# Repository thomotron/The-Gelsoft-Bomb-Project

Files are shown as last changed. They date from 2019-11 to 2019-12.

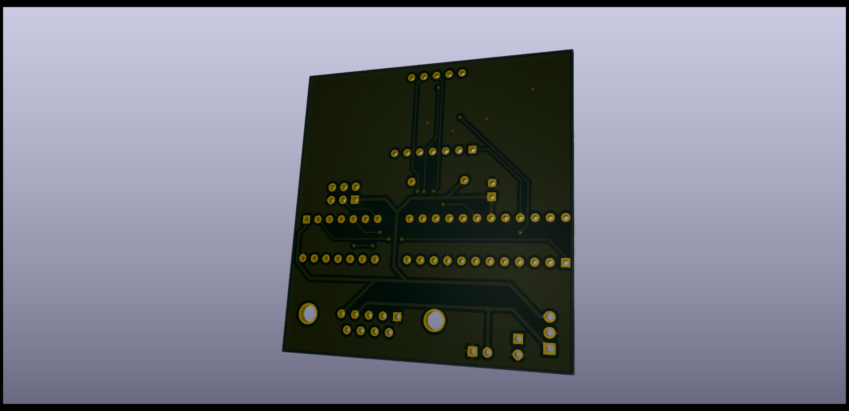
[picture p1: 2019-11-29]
KiCad stuff/The Gelsoft Bomb Project/Case Controller 0.1.0 Back.png

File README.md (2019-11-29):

# The Gelsoft Bomb Project
A [KTANE](https://en.wikipedia.org/wiki/Keep_Talking_and_Nobody_Explodes)-inspired toy bomb for use in [gelsoft](https://en.wikipedia.org/wiki/Gel_ball_shooter) matches.

The core concept is to have a ruggedised case (probably a pistol or camera case like the Pelican Vault V100) that can be opened up to reveal an interactive puzzle and a timer.
If the puzzle is not solved in time, the gelbomb will make a loud beeping noise and stop the timer (sounds lame, but I'm not putting gels in this thing).
This can be incorporated into your own game modes to make things interesting.

The gelbomb It features a highly-modular design, allowing many different puzzle modules to be switched in and out during the course of a day.

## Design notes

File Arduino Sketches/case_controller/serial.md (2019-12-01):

# Core module serial interface
The serial interface with the core module operates on 5v logic using AVR's built-in Universal Serial Interface in three-wire mode (SPI-compatible).
The core module acts as the master serial device, so it provides its own clock source.

Communication is started by first sending a single-byte command from the command table below:

| 7 (MSB) | 6 | 5 | 4 | 3 | 2 | 1 | 0 (LSB) | Command |
| --- | - | - | - | - | - | - | --- | --- |
| 0 | 0 | 0 | 0 | 0 | 0 | 0 | 0 | Do nothing |
| 0 | 0 | 0 | 0 | 0 | 0 | 0 | 1 | Defuse |
| 0 | 0 | 0 | 0 | 0 | 0 | 1 | 0 | Detonate |
| 0 | 0 | 0 | 0 | 0 | 0 | 1 | 1 | Add strike |
| 0 | 0 | 0 | 0 | 0 | 1 | 0 | 0 | Add time |
| 0 | 0 | 0 | 0 | 0 | 1 | 0 | 1 | Remove time |
| 1 | 0 | 0 | 0 | 0 | 1 | 1 | 0 | Get strikes |
| 1 | 0 | 0 | 0 | 0 | 1 | 1 | 1 | Get time remaining  |
| 1 | 0 | 0 | 0 | 1 | 0 | 0 | 0 | Get low power state |

Data is sent as another byte following the command which may be either to or from the core module.
The most-significant bit denotes whether the data will be sent by the core module (Bit 7 = 1) or the puzzle module (Bit 7 = 0).

# Commands
## Defuse
**Command:** `0b00000001`  
**Payload:** No  
Defuses the device, stopping the timer. The device will not accept commands that modify its state while defused.

## Detonate
**Command:** `0b00000010`  
**Payload:** No  
Detonates the device, adding the maximum number of strikes and stopping the timer. The device will not accept commands that modify its state while detonated.

## Add strike
**Command:** `0b00000011`  
**Payload:** No  
Adds one strike. If the number of strikes exceeds the maximum, the device will detonate.

## Add time
**Command:** `0b00000100`  
**Payload:** Yes  
**Direction:** Puzzle-to-core  
Adds up to 5999 seconds to the timer. The timer will not exceed 5999 seconds.
Because this is larger than an 8-bit unsigned integer, the value may be split over two bytes with 7 bits of data each.
The most-significant bit of each byte is used as a flag to expect a following byte with additional data.
If the first byte given has the most-significant bit set to 1, the given bits are shifted left 7 places and another byte will be expected with the remaining 7 bits of data.
These bits are shifted MSB-first into a 16-bit unsigned integer.

**Payload format table:**

| 7 (MSB) | 6 | 5 | 4 | 3 | 2 | 1 | 0 (LSB) | Command |
| --- | - | - | - | - | - | - | --- | --- |
| 0 | a | b | c | d | e | f | g | Add the given bits to the timer |
| 1 | a | b | c | d | e | f | g | Shift bits 0-6 and await 7 more |

## Remove time
**Command:** `0b00000101`  
**Payload:** Yes  
**Direction:** Puzzle-to-core  
Removes up to 5999 seconds from the timer. The timer will not drop below 0 seconds.
Because this is larger than an 8-bit unsigned integer, the value may be split over two bytes with 7 bits of data each.
The most-significant bit of each byte is used as a flag to expect a following byte with additional data.
If the first byte given has the most-significant bit set to 1, the given bits are shifted left 7 places and another byte will be expected with the remaining 7 bits of data.
These bits are shifted MSB-first into a 16-bit unsigned integer.

**Payload format table:**

| 7 (MSB) | 6 | 5 | 4 | 3 | 2 | 1 | 0 (LSB) | Command |
| --- | - | - | - | - | - | - | --- | --- |
| 0 | a | b | c | d | e | f | g | Remove the given bits from the timer |
| 1 | a | b | c | d | e | f | g | Shift bits a-g and await 7 more |

## Get strikes
**Command:** `0b10000110`  
**Payload:** Yes  
**Direction:** Core-to-puzzle  
Gets the current number of strikes as an 8-bit unsigned integer.

**Payload format table:**

| 7 (MSB) | 6 | 5 | 4 | 3 | 2 | 1 | 0 (LSB) | Command |
| --- | - | - | - | - | - | - | --- | --- |
| a | b | c | d | e | f | g | h | Number of strikes |

## Get time remaining
**Command:** `0b10000111`  
**Payload:** Yes  
**Direction:** Core-to-puzzle  
Gets the current amount of time remaining.
Because this is larger than an 8-bit unsigned integer, the value may be split over two bytes with 7 bits of data each.
The most-significant bit of each byte is used as a flag to expect a following byte with additional data.
If the first byte received has the most-significant bit set to 1, the remaining bits are shifted left 7 places and another byte should be expected with the remaining 7 bits of data.
These bits should be shifted MSB-first into a 16-bit unsigned integer.

**Payload format table:**

| 7 (MSB) | 6 | 5 | 4 | 3 | 2 | 1 | 0 (LSB) | Command |
| --- | - | - | - | - | - | - | --- | --- |
| 0 | a | b | c | d | e | f | g | Remaining time |
| 1 | a | b | c | d | e | f | g | Shift bits a-g and await 7 more |

## Get low power state
**Command:** `0b10001000`  
**Payload:** Yes  
**Direction:** Core-to-puzzle  
Gets whether the device is in low-power mode. When the device is in low-power mode, all high-current

**Payload format table:**

| 7 (MSB) | 6 | 5 | 4 | 3 | 2 | 1 | 0 (LSB) | Command |
| --- | - | - | - | - | - | - | --- | --- |
| X | X | X | X | X | X | X | 1 | Low power is enabled  |
| X | X | X | X | X | X | X | 0 | Low power is disabled |

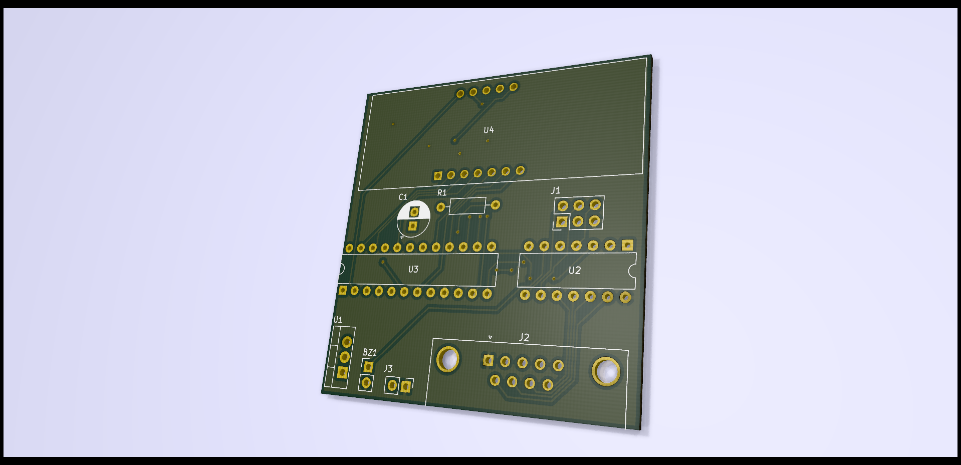
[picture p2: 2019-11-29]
KiCad stuff/The Gelsoft Bomb Project/Case Controller 0.1.0 Front.png

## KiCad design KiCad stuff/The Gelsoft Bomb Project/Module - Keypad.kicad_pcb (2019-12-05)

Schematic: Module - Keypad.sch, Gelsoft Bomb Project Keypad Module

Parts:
J1: ISP; PinHeader_2x03_P2.54mm_Vertical
J2: Module Connector; PinHeader_1x09_P1.27mm_Vertical
R1: 10k; R_Axial_DIN0614_L14.3mm_D5.7mm_P20.32mm_Horizontal
U1: ATmega8-16PU; DIP-28_W7.62mm
U2: 74HC595; DIP-16_W7.62mm
U3: 3x4_Keypad; PinHeader_1x07_P2.54mm_Vertical
U4: MC11605A6W7-BNMLW; PinHeader_1x16_P2.54mm_Vertical

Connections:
5v: J1.1, J2.9, U1.7 (VCC), U2.16 (VCC), U4.2, U4.15
Earth: J1.5, J2.1, J2.2, J2.6, J2.7, R1.2, U1.8 (GND), U2.8 (GND), U4.1
MISO: J1.2, J2.4, U1.18 (PB4)
MOSI: J1.3, J2.3, U1.17 (PB3)
unnamed: R1.1, U4.3
unnamed: U1.2 (PD0), U4.6
unnamed: U1.3 (PD1), U3.3
unnamed: U1.4 (PD2), U3.1
unnamed: U1.5 (PD3), U3.5
unnamed: U1.6 (PD4), U3.2
unnamed: U1.10 (PB7/XTAL2), U2.10 (~SRCLR)
unnamed: U1.11 (PD5), U3.7
unnamed: U1.12 (PD6), U3.6
unnamed: U1.13 (PD7), U3.4
unnamed: U1.23 (PC0), U2.14 (SER)
unnamed: U1.24 (PC1), U2.11 (SRCLK)
unnamed: U1.25 (PC2), U2.12 (RCLK)
unnamed: U1.26 (PC3), U4.16
unnamed: U1.27 (PC4), U4.4
unnamed: U1.28 (PC5), U4.5
unnamed: U2.1 (QB), U4.8
unnamed: U2.2 (QC), U4.9
unnamed: U2.3 (QD), U4.10
unnamed: U2.4 (QE), U4.11
unnamed: U2.5 (QF), U4.12
unnamed: U2.6 (QG), U4.13
unnamed: U2.7 (QH), U4.14
unnamed: U2.15 (QA), U4.7
RESET: J1.6, U1.1 (PC6/~RESET)
SCK: J1.4, J2.5, U1.19 (PB5)
VIN: J2.8

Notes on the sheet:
Keypad
LCD Enable
Shift Reg.
LCD Mode/LED

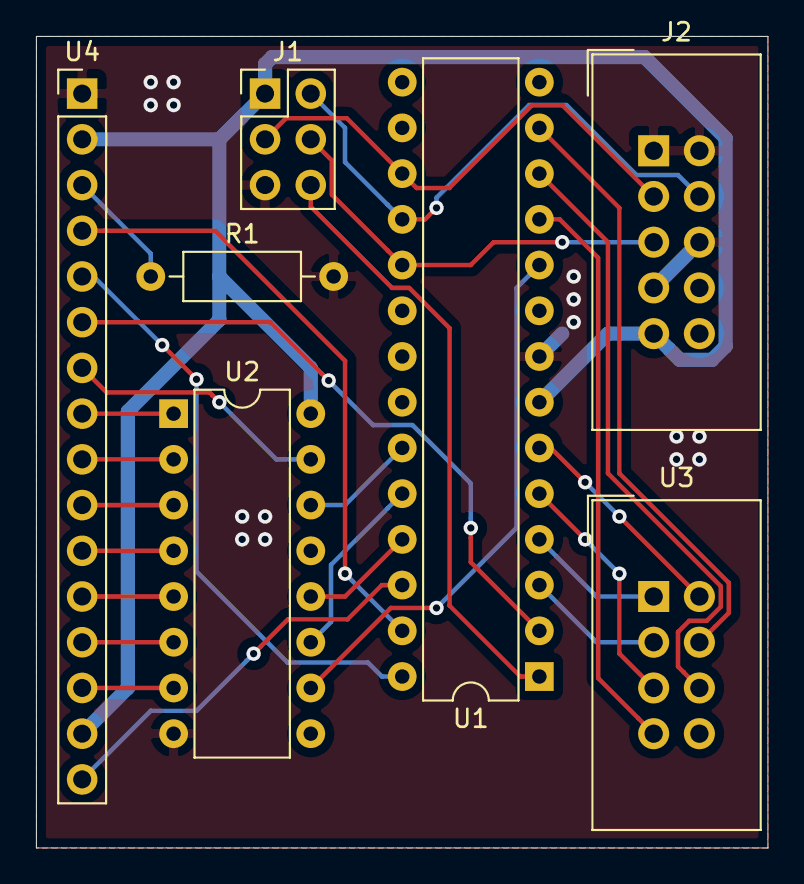
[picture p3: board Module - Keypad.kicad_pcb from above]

Board: 2 copper layers, 40.6 x 45.1 mm, 7 parts (0 on the bottom side), 30 nets.

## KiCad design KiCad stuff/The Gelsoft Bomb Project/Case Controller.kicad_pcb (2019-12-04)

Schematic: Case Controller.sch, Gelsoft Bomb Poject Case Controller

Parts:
BZ1: Buzzer; PinHeader_1x02_P2.54mm_Vertical
C1: 470uF; CP_Radial_D10.0mm_P5.00mm
D1: 1N5400; D_DO-201AD_P15.24mm_Horizontal
D2: STRIKE 1; LED_Square_15x15mm
D3: STRIKE 2; LED_Square_15x15mm
J1: ISP; PinHeader_2x03_P2.54mm_Vertical
J2: Module Connector; DSUB-9_Male_Horizontal_P2.77x2.84mm_EdgePinOffset4.94mm_Hou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
J3: Battery Header; PinHeader_1x02_P2.54mm_Vertical
J4: Low-Power Switch; PinHeader_1x02_P2.54mm_Vertical
R1: 20k; R_Axial_DIN0207_L6.3mm_D2.5mm_P10.16mm_Horizontal
R5, R6, R7, R8: 100k; R_Axial_DIN0207_L6.3mm_D2.5mm_P10.16mm_Horizontal
SW1: Power Switch; SK12D07VG3
SW2: PLUS; SW_PUSH_6mm
SW3: MINUS; SW_PUSH_6mm
SW4: OK; SW_PUSH_6mm
U1: Buck_Converter_Module_7-26v; Buck_Converter_Module_7-24v
U2: ATtiny24A-PU; DIP-14_W7.62mm
U3: MAX7219; DIP-24_W7.62mm
U4: HDSP-B09G; HDSP-B08G

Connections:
5v: C1.1, J1.1, J2.9, R1.2, R5.2, SW2.1, SW3.1, SW4.1, U1.3, U2.1, U3.19
BUZZER: BZ1.1, U2.6
Earth: BZ1.2, C1.2, J1.5, J2.1, J2.2, J2.6, J2.7, J3.1, U1.2, U1.4, U2.14, U3.4, U3.9
LOWPOWER: J4.1, U2.13
MINUS: R7.1, U2.11
MISO: J1.2, J2.4, U2.8
MOSI: J1.3, J2.3, U2.7
unnamed: D1.2, SW1.1
unnamed: D2.1, U3.2, U4.12
unnamed: D2.2, D3.2, U3.22, U4.3
unnamed: D3.1, U3.7, U4.6
unnamed: J3.2, SW1.2
unnamed: J4.2, R5.1
unnamed: R1.1, U3.18
unnamed: R6.2, SW2.2
unnamed: R7.2, SW3.2
unnamed: R8.2, SW4.2
unnamed: U2.2, U3.1
unnamed: U2.3, U3.13
unnamed: U2.5, U3.12
unnamed: U3.6, U4.8
unnamed: U3.11, U4.9
unnamed: U3.14, U4.11
unnamed: U3.15, U4.10
unnamed: U3.16, U4.7
unnamed: U3.17, U4.5
unnamed: U3.20, U4.4
unnamed: U3.21, U4.1
unnamed: U3.23, U4.2
OK: R8.1, U2.10
PLUS: R6.1, U2.12
RESET: J1.6, U2.4
SCK: J1.4, J2.5, U2.9
VIN: D1.1, J2.8, U1.1

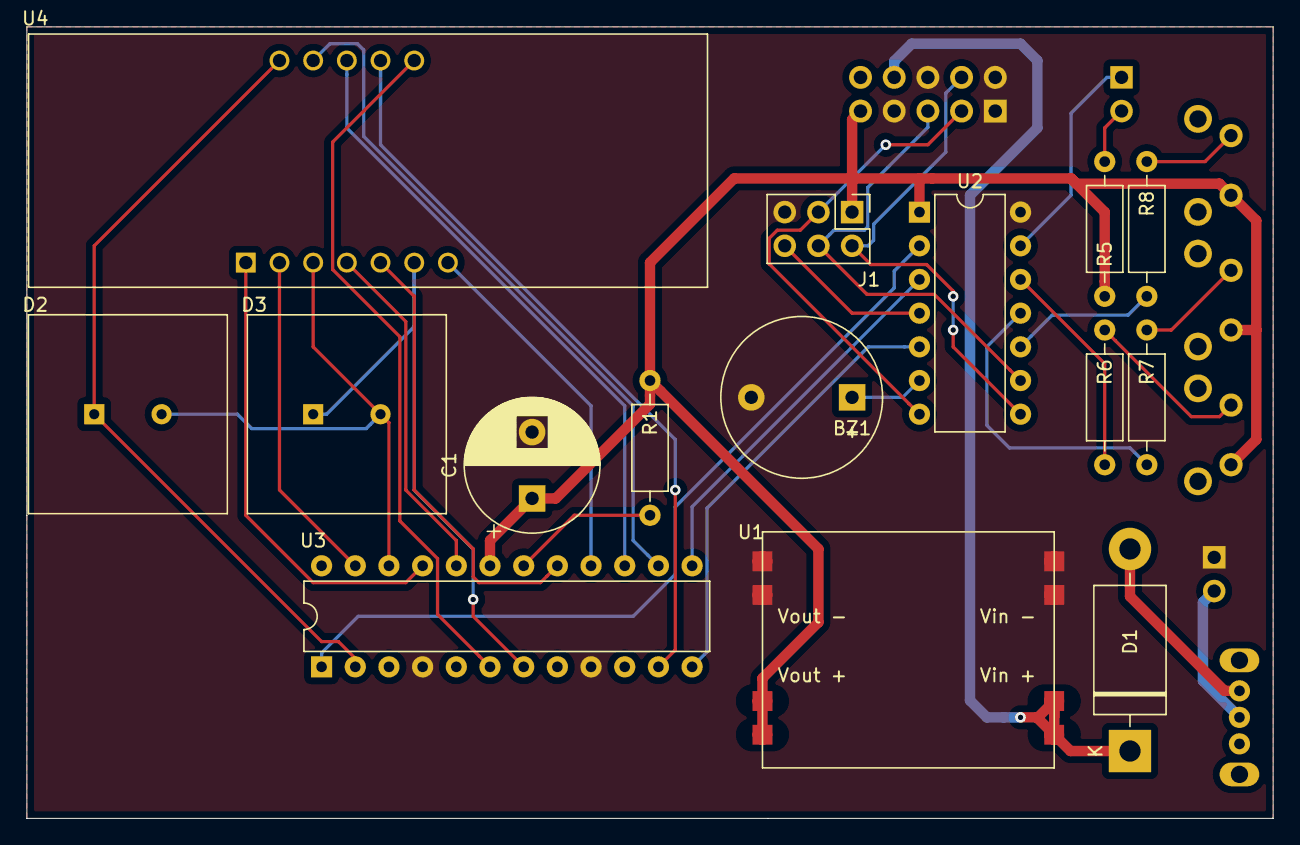
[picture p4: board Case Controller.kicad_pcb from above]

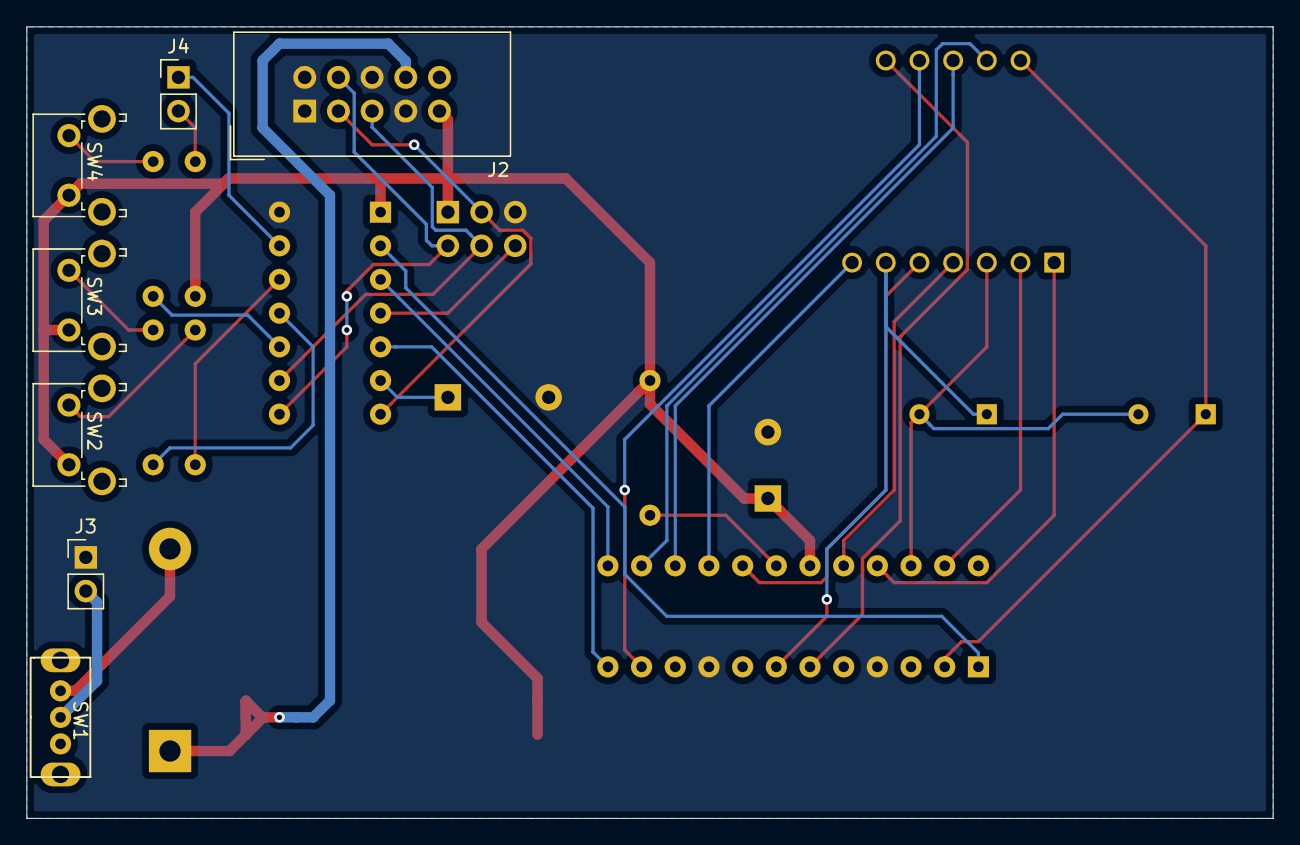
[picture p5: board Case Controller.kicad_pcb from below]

Board: 2 copper layers, 94.0 x 59.7 mm, 22 parts (7 on the bottom side), 34 nets.

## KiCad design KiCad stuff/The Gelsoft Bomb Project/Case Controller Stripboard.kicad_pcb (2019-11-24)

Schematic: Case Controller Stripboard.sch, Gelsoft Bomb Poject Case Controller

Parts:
BZ1: Buzzer; PinHeader_1x02_P2.54mm_Vertical
C1: 100uF; CP_Radial_D6.3mm_P2.50mm
J1: ISP; PinHeader_2x03_P2.54mm_Vertical
J2: Module Connector; DSUB-9_Male_Horizontal_P2.77x2.84mm_EdgePinOffset4.94mm_Hou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
J3: Battery Header; PinHeader_1x02_P2.54mm_Vertical
J4, J5: Conn_01x07; PinSocket_1x07_P2.54mm_Vertical
R1: 20k; R_Axial_DIN0207_L6.3mm_D2.5mm_P10.16mm_Horizontal
U1: L7805; TO-220-4_Vertical
U2: ATtiny24A-PU; DIP-14_W7.62mm
U3: MAX7219; DIP-24_W7.62mm
U4: HDSP-B09G; HDSP-B08G

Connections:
5v: C1.1, J1.1, J2.5, J4.1, R1.2, U1.3, U2.1, U3.19
BUZZER: BZ1.1, J4.6, U2.6
CORRECT: J2.6, J5.6, U2.13
DISARM: J2.8, J5.4, U2.11
GND: BZ1.2, C1.2, J2.1, J3.1, J5.7, U1.2, U2.14, U3.4, U3.9
LOWPOWER: J2.9, J5.3, U2.10
MISO: J5.1, U2.8
MOSI: J4.7, U2.7
unnamed: R1.1, U3.18
unnamed: U3.2, U4.12
unnamed: U3.6, U4.8
unnamed: U3.7, U4.6
unnamed: U3.11, U4.9
unnamed: U3.14, U4.11
unnamed: U3.15, U4.10
unnamed: U3.16, U4.7
unnamed: U3.17, U4.5
unnamed: U3.20, U4.4
unnamed: U3.21, U4.1
unnamed: U3.22, U4.3
unnamed: U3.23, U4.2
Pin2: J4.2, U2.2, U3.1
Pin3: J4.3, U2.3, U3.13
Pin5: J4.5, U2.5, U3.12
RESET: J4.4, U2.4
SCK: J5.2, U2.9
STRIKE: J2.7, J5.5, U2.12
VIN: J2.4, J3.2, U1.1

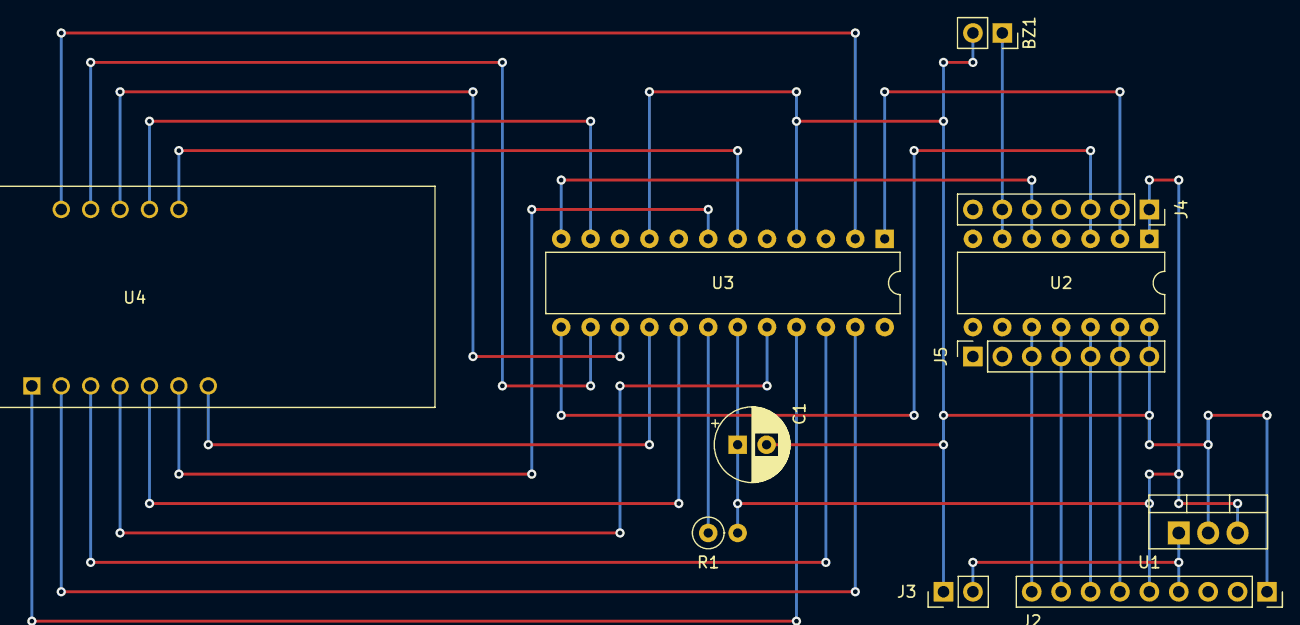
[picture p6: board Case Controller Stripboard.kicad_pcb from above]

Board: 2 copper layers, 11 parts (0 on the bottom side), 28 nets.

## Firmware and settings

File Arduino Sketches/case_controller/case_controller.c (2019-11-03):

// This file is written to correspond with the
// following pinout:
//
//                    ATTiny24A
//                   .----v----.
//              Vcc -| 1    14 |- GND
// B0   MAX7219 DIN -| 2    13 |- CORRECT IN    A0
// B1   MAX7219 CLK -| 3    12 |- STRIKE IN     A1
// B3     ISP RESET -| 4    11 |- DISARM OUT    A2
// B2  MAX7219 LOAD -| 5    10 |- LOWPOWER OUT  A3
// A7        BUZZER -| 6     9 |- ISP SCK       A4
// A6      ISP MOSI -| 7     8 |- ISP MISO      A5
//                   *---------*

#include <avr/io.h>
#include <avr/interrupt.h>
#include <util/delay.h>
#include <stdbool.h>
#include "max7219.c"

// Define some macros for the DIN, CLK, and LOAD connections to the MAX2719
#define DIN_PORT PORTB
#define DIN_PIN  0
#define CLK_PORT PORTB
#define CLK_PIN  1
#define LOAD_PORT PORTB
#define LOAD_PIN 2

// Define some macros for the interrupt pins
#define CORRECT_PORT PORTA
#define CORRECT_PIN  0
#define STRIKE_PORT PORTA
#define STRIKE_PIN  1

// Define some macros for other pins
#define BUZZER_PORT PORTA
#define BUZZER_PIN 7

// Function prototypes
void init();
void onCorrect();
void onStrike();
void enableInterrupts();
void disableInterrupts();
void enableInterrupt(int interrupt);
void disableInterrupt(int interrupt);
void writeBit(bool bit);
void writeByteMSB(unsigned char byte);
void displayTimeRemaining();
void updateDisplay();
void beep(int duration);

// State variables
bool running = true;
volatile bool solved = false;
volatile int strikes = 0;
const int maxStrikes = 3;
int timeRemaining = 300; // 5-minute countdown
bool displayBlinking = false;
bool displayBlankedLast = false;

// Interrupt states
bool correctPinLast;
bool strikePinLast;

// Define interrupt handler
ISR(PCINT0_vect)
{
    // Get current interrupt pin states
    bool correctPin = (CORRECT_PORT >> CORRECT_PIN) & 1;
    bool strikePin = (STRIKE_PORT >> STRIKE_PIN) & 1;

    // Compare and run handlers
    if (correctPinLast != correctPin) onCorrect();
    if (strikePinLast != strikePin) onStrike();

    // Shift states to history for the next run
    correctPinLast = correctPin;
    strikePinLast = strikePin;
}

void init()
{
    // Set port I/O directions
    DDRA |= 0b11000000;
    DDRB |= 0b00000000;

    // Set up interrupt registers and enable PCINT0 and PCINT1
    enableInterrupts();
    enableInterrupt(0);
    enableInterrupt(1);

    // Initialise the LED display
    MAX7219_Init();

    // Test the display for one second
    MAX7219_DisplayTestStart();
    _delay_ms(1000);
    MAX7219_DisplayTestStop();
    MAX7219_Clear();
}

int main() {
    // Initialise everything
    init();

    // Enter the Main Run Loop (MRL) -- Advanced military tech right here
    while (running)
    {
        int delay_ms = 1000;

        // Decrement time remaining by 1 second
        timeRemaining--;

        // Update the display based on our current state
        updateDisplay();

        // Check if we should detonate
        if (timeRemaining < 0 || strikes == maxStrikes)
        {
            // Disable interrupts and clear running flag
            disableInterrupt(0);
            disableInterrupt(1);
            running = false;

            // TODO: Detonate more spectacularly
            // For now, we'll just make a nice long beep
            beep(3000);

            // Reached an end condition, break out
            break;
        }
        // Check if we've been solved
        else if (solved)
        {
            // Disable interrupts and clear running flag
            disableInterrupt(0);
            disableInterrupt(1);
            running = false;

            // Reached an end condition, break out
            break;
        }

        // Beep the buzzer if running
        if (timeRemaining >= 0) {
            beep(50);
            delay_ms -= 50;
        }

        // Wait until we have no delay left
        while (delay_ms-- > 0) _delay_ms(1);
    }

    // Loop forever until we're reset
    while (true) continue;
}

void updateDisplay()
{
    // Blinking logic
    // Check if this is the blanking part of the blink cycle if we are blinking
    if (displayBlinking && !displayBlankedLast)
    {
        // Blank the display and set the blanked flag
        MAX7219_Clear();
        displayBlankedLast = true;

        // Stop here
        return;
    }
    else
    {
        // Reset the blanked flag
        displayBlankedLast = false;
    }

    // Actually update the display with content
    // Check which message we should display
    if (strikes == maxStrikes || timeRemaining < 0) // Are we dead?
    {
        // Write 'DEAD'
        MAX7219_DisplayChar(1, 'D', false);
        MAX7219_DisplayChar(2, 'E', false);
        MAX7219_DisplayChar(3, 'A', false);
        MAX7219_DisplayChar(4, 'D', false);
    }
    else
    {
        // Write remaining time
        displayTimeRemaining();
    }
}

void displayTimeRemaining()
{
    // Check if we have passed the point of no return
    if (timeRemaining < 0)
    {
        // 'Line-out' the display since we can't do negative numbers
        for (int i = 1; i <= 4; i++)
        {
            MAX7219_DisplayChar(i, '-', false);
        }
    }
    else
    {
        // Split the remaining time down into digits and display them
        int minutes = timeRemaining / 60;
        int seconds = timeRemaining - (minutes * 60);
        MAX7219_DisplayChar(1, (char) ((int)(minutes / 10) + 48), false); // Values are offset by 48 for ASCII
        MAX7219_DisplayChar(2, (char) ((int)(minutes % 10) + 48), true); // DP enabled to show a ':'
        MAX7219_DisplayChar(3, (char) ((int)(seconds / 10) + 48), true); // between digits 2 and 3
        MAX7219_DisplayChar(4, (char) ((int)(seconds % 10) + 48), false);
    }
}

void onCorrect()
{
    solved = true;
}

void onStrike()
{
    strikes = ++strikes > maxStrikes ? maxStrikes : strikes; // Cap strikes at maxStrikes
}

void enableInterrupts()
{
    // Enable global interrupts by setting SREG[7] to 1
    SREG |= (1 << 7);

    // Enable interrupt group PCINT[0-7] by setting GIMSK[4] to 1
    GIMSK |= (1 << 4);
}

void disableInterrupts()
{
    // Disable global interrupts by setting SREG[7] to 0
    SREG &= ~(1 << 7);

    // Disable interrupt group PCINT[0-7] by setting GIMSK[4] to 0
    GIMSK &= ~(1 << 4);
}

// Enables an interrupt pin in the PCINT[0-7] group
void enableInterrupt(int interrupt)
{
    // Enable interrupt pin by setting PCMSK0[interrupt] to 1
    PCMSK0 |= (1 << interrupt);
}

// Disables an interrupt pin in the PCINT[0-7] group
void disableInterrupt(int interrupt)
{
    // Disable interrupt pin by setting PCMSK0[interrupt] to 0
    PCMSK0 &= ~(1 << interrupt);
}

// Writes a single bit to the given port on the given pin
//   bit: Bit to write
void writeBit(bool bit)
{
    // Set or clear the pin, depending on the bit
    if (bit) DIN_PORT |= bit << DIN_PIN;
    else DIN_PORT &= ~(bit << DIN_PIN);

    // Pulse the clock
    CLK_PORT |= 1 << CLK_PIN;
    CLK_PORT &= ~(1 << CLK_PIN);
}

// Writes a single byte to the given port on the given pin (MSB-first)
//   byte: Byte to write
void writeByteMSB(unsigned char byte)
{
    // Iterate from MSB to LSB
    for (int i = 7; i >= 0; i--)
    {
        // Mask the relevant bit and write it
        writeBit(byte & (1 << i));
    }
}

// Beeps for the given number of milliseconds
void beep(int duration)
{
    // Write the pin high
    BUZZER_PORT |= 1 << BUZZER_PIN;

    // Hacky workaround for runtime-variable delay
    while (duration-- > 0) _delay_ms(1);

    // Write the pin low
    BUZZER_PORT &= ~(1 << BUZZER_PIN);
}

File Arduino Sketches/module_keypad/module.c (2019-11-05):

// This file is written to correspond with the
// following pinout:
//
//                     ATMega8
//                   .----v----.
// C6         RESET -| 1    28 |- LCD R/W       C5
// D0    LCD ENABLE -| 2    27 |- LCD REG SEL   C4
// D1   KEYPAD COL1 -| 3    26 |- LCD LED SINK  C3
// D2   KEYPAD COL2 -| 4    25 |- LCD STOR CLK  C2
// D3   KEYPAD COL3 -| 5    24 |- LCD SHFT CLK  C1
// D4   KEYPAD ROW1 -| 6    23 |- LCD DATA      C0
//              Vcc -| 7    22 |- GND
//              GND -| 8    21 |- AREF
// B6   LOWPOWER IN -| 9    20 |- AVCC
// B7  LCD SHFT CLR -| 10   19 |- ISP SCK       B5
// D5   KEYPAD ROW2 -| 11   18 |- ISP MISO      B4
// D6   KEYPAD ROW3 -| 12   17 |- ISP MOSI      B3
// D7   KEYPAD ROW4 -| 13   16 |- DISARM IN     B2
// B0   CORRECT OUT -| 14   15 |- STRIKE OUT    B1
//                   *---------*

#include <avr/io.h>
#include <avr/pgmspace.h>
#include <util/delay.h>
#include <stdbool.h>
#include "randomvals.h"

// Define some macros for the LCD_DATA, LCD_SHFT, and LCD_STOR connections to the SN74HC595
#define LCD_DATA_PORT PORTB
#define LCD_DATA_PIN  0
#define LCD_SHFT_PORT PORTB
#define LCD_SHFT_PIN  1
#define LCD_STOR_PORT PORTC
#define LCD_STOR_PIN 2

// Define some macros for the interrupt pins
#define DISARM_PORT PORTB
#define DISARM_PIN  2
#define LOWPOWER_PORT PORTB
#define LOWPOWER_PIN  6

// Define some macros for other pins
#define LCD_BACKLIGHT_PORT PORTC
#define LCD_BACKLIGHT_PIN 3

// Define some macros for the keypad pins
#define KEY_COL1_PORT PORTD
#define KEY_COL1_PIN 1
#define KEY_COL2_PORT PORTD
#define KEY_COL2_PIN 2
#define KEY_COL3_PORT PORTD
#define KEY_COL3_PIN 3
#define KEY_ROW1_PORT PORTD
#define KEY_ROW1_PIN 4
#define KEY_ROW2_PORT PORTD
#define KEY_ROW2_PIN 5
#define KEY_ROW3_PORT PORTD
#define KEY_ROW3_PIN 6
#define KEY_ROW4_PORT PORTD
#define KEY_ROW4_PIN 7

// Define some macros for sequence generation
#define SEQUENCE_LENGTH ((unsigned char) 7)

// Define some macros for type shortcuts
#define byte unsigned char

// Function prototypes
void init();
int main();
void onDisarm(bool disarm);
void onLowPower(bool enabled);
void writeBit(bool bit);
void writeByteMSB(byte b);
byte getRandom();
void generateSequence();
void updateKeypadState();
bool readKeypadKey(unsigned char port, unsigned char row_pin, unsigned char column_pin);
byte getNumKeysPressed();
bool getKeypadKey(char key);

// Consts
const char keypadChars[] = {'0','1','2','3','4','5','6','7','8','9','*','#'};
const byte sequenceLength = SEQUENCE_LENGTH;

// State variables
bool running = true;
unsigned short ptrRnd = 0;
char sequence[SEQUENCE_LENGTH];
byte sequenceIndex;

// Interrupt states
bool disarmPinLast;
bool lowPowerPinLast;

// Keypad state
bool keypadState[4][3] =
{
    { // Row 1
        false, // Button 1
        false, // Button 2
        false  // Button 3
    },
    { // Row 2
        false, // Button 4
        false, // Button 5
        false  // Button 6
    },
    { // Row 3
        false, // Button 7
        false, // Button 8
        false  // Button 9
    },
    { // Row 4
        false, // Button 10
        false, // Button 11
        false  // Button 12
    }
};
byte numKeysPressed = 0;

void init()
{
    // Set port I/O directions (0 = in, 1 = out)
    DDRB |= 0b10010011;
    DDRC |= 0b0111111;
    DDRD |= 0b00001111;

    // Populate the sequence buffer with random keypad characters
    generateSequence();
}

int main() {
    // Initialise everything
    init();

    // Enter the Main Run Loop (MRL) -- Advanced military tech right here
    while (running)
    {
        // Check if we should disarm or enter low power mode
        bool disarmPin = (DISARM_PORT >> DISARM_PIN) & 1;
        bool lowPowerPin = (LOWPOWER_PORT >> LOWPOWER_PIN) & 1;

        // Call handlers if the pin state has changed
        if (disarmPin != disarmPinLast) onDisarm(disarmPin);
        if (lowPowerPin != lowPowerPinLast) onLowPower(lowPowerPin);

        // Shift the current state into history
        lowPowerPinLast = lowPowerPin;
        disarmPinLast = disarmPin;

        // Update the keypad state and check it against the current sequence
        updateKeypadState();
        if (getNumKeysPressed == 1 && getKeypadKey(sequence[sequenceIndex]))
        {
            // Move to the next item in the sequence
            sequenceIndex++;

            // Check if we have finished the sequence
            if (sequenceIndex == sequenceLength)
            {
                // TODO: Mark as defused
            }

            // TODO: Update the LCD
        }
    }

    // Loop forever until reset
    while (true) continue;
}

// Handler for disarming the module
void onDisarm(bool disarm)
{
    // TODO: Write defused message to display and stop running
}

// Handler for setting low power state
void onLowPower(bool enabled)
{
    // Source current to the backlight -ve
    if (enabled) LCD_BACKLIGHT_PORT &= ~(1 << LCD_BACKLIGHT_PIN);
    // Sink current from the backlight -ve
    else LCD_BACKLIGHT_PORT |= (1 << LCD_BACKLIGHT_PIN);
}

// Writes a single bit to the given port on the given pin
//   bit: Bit to write
void writeBit(bool bit)
{
    // Set or clear the pin, depending on the bit
    if (bit) LCD_DATA_PORT |= bit << LCD_DATA_PIN;
    else LCD_DATA_PORT &= ~(bit << LCD_DATA_PIN);

    // Pulse the clock
    LCD_SHFT_PORT |= 1 << LCD_SHFT_PIN;
    LCD_SHFT_PORT &= ~(1 << LCD_SHFT_PIN);
}

// Writes a single byte to the given port on the given pin (MSB-first)
//   byte: Byte to write
void writeByteMSB(byte b)
{
    // Iterate from MSB to LSB
    for (int i = 7; i >= 0; i--)
    {
        // Mask the relevant bit and write it
        writeBit(b & (1 << i));
    }
}

// Read a random value from randomvals.h, wrap when reaching the end of the table.
byte getRandom()
{
    byte rnd = pgm_read_byte(&(random0[ptrRnd++]));

    if (ptrRnd == sizeof(random0)) ptrRnd = 0;

    return rnd;
}

// Populates the sequence buffer with random keypad characters
void generateSequence()
{
    for (int i = 0; i < sequenceLength; i++)
    {
        // Get a random keypad character and append it
        sequence[i] = keypadChars[getRandom() % 13];
    }
}
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

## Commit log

2019-09-06 Add Arduino sketches
2019-09-06 Add KiCad files
    [The Bomb Project.kicad_pcb, The Bomb Project.sch]
2019-09-07 Rename .ino to .c and fix indentation
    [case_controller.c]
2019-09-07 WIP: Add initial schematic
    [The Bomb Project.sch]
2019-09-08 Add and use HT16K33
    [The Bomb Project.sch]
2019-09-08 Add and use MAX7219
    Chips ahoy!
    Finally found the one we should be using. The 7219 supports up to 8 digits *including* decimal places *and* it uses a shift register with latches and current sourcing/sinking built in! It's the perfe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
    [The Bomb Project.sch]
2019-09-08 Downgrade MCU to an ATTiny24A
    We don't need all of the extra features on a Mega328P, the Tiny24A should do it just fine
    [The Bomb Project.sch]
2019-09-08 Add RS232 connector and finalise schematic
    [The Bomb Project.sch]
2019-09-08 Add battery connector
    [The Bomb Project.sch]
2019-09-08 Add VIN to module connector
    Should be more flexible if modules want to draw more juice or supply some extra
    [The Bomb Project.sch]
2019-09-08 Annotate case controller schematic
    [The Bomb Project.sch]
2019-09-08 Associate footprints with each component
    [The Bomb Project.sch]
2019-09-08 Create first case controller PCB prototype
    [The Bomb Project.kicad_pcb]
2019-09-08 Move vias
    [The Bomb Project.kicad_pcb]
2019-09-08 Rename project files
    [Case Controller.kicad_pcb, Case Controller.sch]
2019-09-09 Rework case controller code for avr-libc and avr-gcc
    [case_controller.c]
2019-09-09 Handle interrupts
2019-09-09 Update function prototypes
2019-09-09 Add custom digit struct and replace arrays in writeDigits function
    [case_controller.c]
2019-09-09 Add flash and fuse make targets
2019-09-10 Use MAX7219 library and implement LED countdown
2019-09-10 Add buzzer to countdown
    [case_controller.c]
2019-09-16 Add keypad module schematic and parts
    [Module - Keypad.kicad_pcb, Module - Keypad.sch]
2019-10-12 Finalise the keypad module and add a PCB design
    [Module - Keypad.kicad_pcb, Module - Keypad.sch]
2019-10-13 Add a new LCD and replace the old one
    [Module - Keypad.sch]
2019-10-13 Ignore KiCad backups
2019-11-02 Fix issue where some digits would not illuminate
    Turns out the library was wrong, it was shifting by the digit number instead of using the number in BCD (i.e. digit 3 is 0011)
    [max7219.c]
2019-11-02 Add missing prototype
2019-11-03 Add decoupling cap to the MAX7219
    It makes an unbearable noise on the buzzer if left untreated
    [Case Controller.sch]
2019-11-05 Fix variably-defined array issue
    Arrays like to be compile-time constant, so use a define instead
    [module.c]
2019-11-05 Use correct pin variable
    [module.c]
2019-11-24 Board tweaks
    [Case Controller.kicad_pcb, Case Controller.sch]
2019-11-24 Add stripboard adaptation of the case controller circuit
    [Case Controller Stripboard.kicad_pcb, Case Controller Stripboard.sch]
2019-11-28 Revise case controller
    Added a buck converter for more efficient power regulation
    Added a diode to the battery for safety
    Added a power switch
    Reworked the PCB design to suit these upgrades
    [Buck Converter.sch, Case Controller.kicad_pcb, Case Controller.sch]
2019-11-29 Add v0.1.0 board screenshots
2019-12-01 Overhaul into v0.2.0 (see desc)
    Added buttons to set the timer
    Added the low-power switch
    Added strike LEDs (2 for now, since we don't want another LED driver)
    [Case Controller.kicad_pcb, Case Controller.sch]
2019-12-01 Replace buck converter with a pre-made module
    Bugger having to deal with making my own, we'll just keep things simple and cheap
    [Case Controller.kicad_pcb, Case Controller.sch]
2019-12-03 Update footprints and use new layout
    [Case Controller.kicad_pcb]
2019-12-04 Route PCB
    [Case Controller.kicad_pcb]
2019-12-05 Update keypad with new connector pinout
    [Module - Keypad.sch]
2019-12-05 Revise PCB for new pinout
    [Module - Keypad.kicad_pcb]
2019-12-05 Use better footprints
    [Module - Keypad.sch]
